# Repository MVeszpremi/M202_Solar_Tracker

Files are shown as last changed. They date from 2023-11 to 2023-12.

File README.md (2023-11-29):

# AI-Enabled Solar Tracker System
This is the repository for the dual axis tracking system for solar panels. 

Navigation:

* doc/ for website content
* software/ for code used in your project
* software/Full_System_Implementation the main code running to perform the system operation
* data/ for data data used in your project

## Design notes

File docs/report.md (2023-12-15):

<script src="https://polyfill.io/v3/polyfill.min.js?features=es6"></script>
<script id="MathJax-script" async src="https://cdn.jsdelivr.net/npm/mathjax@3/es5/tex-mml-chtml.js"></script>

# Table of Contents
* Abstract
* [Introduction](#1-introduction)
* [Related Work](#2-related-work)
* [Technical Approach](#3-technical-approach)
* [Evaluation and Results](#4-evaluation-and-results)
* [Discussion and Conclusions](#5-discussion-and-conclusions)
* [References](#6-references)

# Abstract

This project details the development of an automated solar tracking system to optimize energy harvesting efficiency. A mechanical positioning apparatus with two stepper motors and a robust dual-axis gimbal precisely rotates the solar panel to continually align perpendicular to sunlight. This maximizes irradiation absorption as the sun shifts. A fisheye lens camera affixed to the panel captures wide-angle sky images every ten seconds. Custom algorithms then analyze the images to track the sun’s location and detect obstructions from cloud cover. Using geometric calculations that account for the system's mechanical constraints, the software continuously updates the optimal orientation by adjusting pitch and yaw of the panel. Additionally, integration of real-time weather data warns of impending storms. This allows the panel to enter "Protection Mode", preemptively tilting panels vertically to defend against hail damage. Empirical testing proves this automated tracking and responsive adaptation achieves substantial efficiency gains over fixed installations, increasing energy output by approximately 30%. The precision positioning not only optimizes solar absorption but also boosts panel longevity and resilience by avoiding atmospheric threats. Moreover, heightened energy capture accelerates return-on-investment for consumers. Financial analysis shows expenditures from weather damage repair significantly outweigh tracker implementation costs. Ultimately, augmenting productivity will catalyze more widespread solar adoption to meet rising renewable energy demands. This project signifies an unprecedented optimization in self-sustaining solar system management through comprehensive sun-chasing and instantaneous atmospheric adaptation capabilities.

# 1. Introduction

## 1.a. Motivation & Objective

The goal of this project is to increase how much energy solar panels can generate and extend their lifespan. We built a solar tracking system that positions the panels in the optimal direction of sunlight all day. The system mounts the solar panels on a mechanical structure with two rotating joints, controlled by a computer program. The computer looks at images from an upward-facing camera that shows sunlight and cloud positions and calculates how to rotate the panels for the best sun exposure at any moment. By keeping the panels perfectly aligned toward the moving sunlight and adjusting to avoid storm clouds, the system aims to maximize the energy output while protecting the equipment in bad weather. This automated tracking using real-time sky images is intended to boost solar power generation efficiency and longevity through precision sunlight targeting and adaptation to atmospheric conditions over time.

As the world strives to transition toward sustainable energy sources and reduce fossil fuel dependence, solar power stands out as one of the most abundant, affordable, and clean alternatives. However, traditional stationary solar panels fail to maximize potential energy harvesting throughout the day as the sun shifts positions. Our motivation with this dual-axis tracking system is to remedy this inefficiency by dynamically following the sun’s movement to optimize irradiation absorption. Increased energy capture extends the system’s cost-effectiveness and accelerates return-on-investment for consumers. But more broadly, boosting solar efficiency aids wider adoption of renewable technologies, driving down overall carbon emissions. Given projections estimating solar energy could satisfy most electricity demands in coming decades, improving panel productivity will make this clean power vision a reality. Our automated sun-chasing design specifically tackles the intermittency and underutilization problems persisting in solar energy. In doing so, it brings carbon-neutral sunlight harvesting closer to its full potential as a dominant sustainable power source worldwide. 

## 1.b. State of the Art & Limitations

Present-day approaches predominantly employ persistent rotational calibration to locate the most favorable solar exposure angles, supplemented by conventional analog sensors to detect adverse weather. However, existing techniques bear two principal shortcomings:

Firstly, repetitive calibration sweeps across all potential orientations lead to appreciable energy losses, besides operational inefficiency. The recurring movements not only drain power but also signify suboptimal design.

Secondly, using discrete analog sensors, each serving distinct purposes, is outdated. Such multiplicity of components complicates installation and inflates costs. Additionally, despite their usefulness for projection, sensors confront intrinsic data fidelity challenges, especially under extreme weather. Translating their complex, voluminous outputs into actionable intelligence also demands formidable computing resources.

Thus, augmentations to rectify these deficiencies could pave the path for more responsive, economical and simpler systems.

## 1.c. Novelty & Rationale

Devising a dual-axis, photograph-guided solar tracking mechanism signifies an unprecedented transformation within renewables. Its uniqueness stems from aligning panels by continually evaluating real-time images of the sky instead of using predetermined patterns or traditional sensors. This breakthrough approach leverages the prowess of cutting-edge imaging algorithms to perpetually discern solar position, beam angles and atmospheric occlusion with extraordinary accuracy, thereby enabling fully autonomous orientation control for flawless energy harvesting. By transcending beyond conventional static configurations and single-axis trackers, this pioneering concept creates flexibility and efficiency in solar power generation. Its remarkable responsiveness and adaptability promises substantial gains over incumbent technologies. 

Additionally, several factors underline the immense promise within this concept:

Firstly, by enabling ultra-precise solar alignment, the technology guarantees dramatic efficiency upturns and hence, cost-effectiveness. Moreover, the ensuing potential reduction in conventional power dependencies makes it equally worthwhile ecologically and economically.

Secondly, the system’s versatility across geographic regions and weather patterns due to its location-specific adaptation abilities facilitates seamless scalability across residential, commercial, and industrial settings catering to diverse needs.

Finally, with global sustainability goals gathering momentum, this breakthrough fortifies our ability to satisfy the escalating renewable energy demands in a sustainable manner.

## 1.d. Potential Impact

The transformational ramifications of this technology extend far beyond its direct contributions to renewable energy. By thoroughly optimizing solar collection efficiency through ultra-precise tracking and instantaneous atmospheric adaptations, it can catalyze wider adoption across the energy industry. The ensuing upsurge in cleaner power not only accelerates sustainability but also nurtures further innovation within the domain. Additionally, enhanced energy security reduces reliance on conventional fossil fuels, stimulating economic growth through emerging opportunities in associated industries. Ultimately, this breakthrough encapsulates a pivotal advancement capable of spearheading an eco-friendly energy future.

## 1.e. Challenges

Realization of this complex concept demands reconciling mechanical sturdiness with software sophistications:

Mechanically, the apparatus must demonstrate unmatched robustness in routinely reorienting the panels with extreme accuracy while continuously self-calibrating.

Concurrently, the algorithms also present multifaceted challenges. Implementing reliable methodologies for cloud detection and ultraprecise solar positioning is imperative, entailing sophisticated translations between aerial coordinates and corresponding image pixels. Additionally, processing obstructive cloud cover data for informing adaptive tilt optimization poses another constraint.

Also, the absence of diverse weather conditions in the technology's preliminary testing phase impedes further refinements, especially in relatively infrequent but highly complex scenarios like hailstorms that stretch the limitations of visual detection methodologies.

## 1.f. Requirements for Success

1. Solar Engineering Expertise: Comprehensive analysis of solar irradiation intricacies including photovoltaics, panel design, and incident ray optimization.
   
2. Image Recognition and Machine Learning: Highly sophisticated tracking algorithms capable of operationalizing real-time solar positioning data into actionable intelligence.
   
3. Mechanical Engineering: The dual-axis tracker apparatus calls for strong mechanical design ensuring flawless motion capabilities and unmatched robustness against wear and tear.
5. Electrical Engineering: Seamless integration of the mechanical steering system with the solar modules and other wired components.
6. Testing and Validation: Continuous system optimization using both simulation tools and real-world experimentation across diverse atmospheric state.
7. Solar Data Integration: Exact solar positioning inputs are vital to process and embed relevant geospatial and calibration data into the algorithms in a reliable fashion.
8. Safety and Compliance Knowledge: Once proven, understanding pertinent regulatory protocols and environmental legislation is essential before pursuing larger-scale adoption across industries and communities.
9. Project Management: With multilayered technical complexities, coherent coordination across involved domains is imperative for progress.

## 1.g. Metrics of Success

1. Image-Based Tracking Accuracy: Quantify the precision of solar recognition and cloud avoidance by the imaging algorithms.
   
3. Angular Error Rate: Evaluate tracking fidelity by measuring deviations between real and targeted solar alignment.
   
5. Response Time: Assess tracking agility via orientation adjustment lag when solar positioning varies.
6. Efficiency Gain: Benchmark improvements in energy output against conventional solar panels.
7. Algorithm Optimization: Appraise tracking software parameters like processing pace and infrastructure needs.
8. Environmental Robustness: Evaluate performance under diverse atmospheric states like shadows and cloud cover.
9. System Reliability: Monitor anomalies, downtimes, and errors to establish reliability.
10. Code Stability and Maintenance: Audit software upkeep prerequisites by tracing bugs and upgrades.

# 2. Related Work
## 2.a. Papers

**What is Solar Tracking?**

This paper provides a foundational base for beginning to understand solar tracking and the existing technologies. It gives a high level overview of GPS and liquid boiling systems currently in industry. This gave us an initial launch point for application, implementation, and optimization.

**Various Solar Tracking Technologies**

This paper describes how solar panels capture and distribute energy and how they currently utilize single and dual axis tracking systems. It also defines passive and active solar trackers and discusses the advantages of solar tracking and the bright future it entails. With this infomration, we were able to further detail our design and determine the use of an active, dual-axis tracker.

**Sky-Image-Based Solar Forecasting Using Deep Learning**

This study investigates different training strategies for solar forecasting models using ground-based sky images from various global datasets with diverse climate patterns. It compares the performance of local models trained individually on single datasets, global models trained on a fusion of multiple datasets, and knowledge transfer from pre-trained models to new datasets. The results show that local models work well in their respective locations with slight errors and provide a robust template for our project.

**Active Solar-Tracking Systems for Photovoltaic Technology & Implementation**

This journal discusses the significance of solar irradiation for photovoltaic (PV) systems and the benefits of solar tracking in maximizing energy generation. It highlights the limitations of current active sensor-tracking algorithms, including issues with cloudy weather, module positioning after nightfall, and protection from adverse weather conditions. It also suggests incorporating periodic movement and nearly horizontal positioning, offering improved system lifetime and storm damage prevention while maintaining high tracking accuracy which influenced our project design decisions.

**TrueCapture’s New Split Boost Mode**

This article gave us insight into the state-of-the-art in the solar industry. It describes the latest addition to TrueCapture Software known as the "Split Boost", a row-to-row feature designed to maximize energy gain for photovaltaic plants using split-cell solar modules. This innovation leverages the shade-tolerant nature of split-cell modules, adjusting the tracker rows to optimize irradiance on the top half of the modules, resulting in a boost in production, even on flat terrain, with preliminary data showing up to a 1% yield improvement compared to conventional backtracking for specific conditions.

**Solar Tracking Investment Review**

After learning about the technology, we were interested in the financial considerations of actually implementing that technology. This article provides an in depth investment review at the residential and commerical level. Although this project is not heavily concerned with finanical implications, as engineers and entrepreneurs, we wanted to take the time to understand all aspects of our project.

## 2.b. Datasets

Singapore Whole sky IMaging SEGmentation Database

Singapore Whole sky IMaging CATegories Database

## 2.c. Software

Pvlib is used as the Solar Positioning Algorithm (SPA) library

OpenCV is used for general image processing and cloud segmentation

# 3. Technical Approach

**Mechanical System**

The solar panel positioning system was engineered to automatically align with the sun. It incorporates two Nema 17 Stepper motors, each equipped with a 26:1 gearbox, to ensure precise rotation speed and strong holding torque. At the start of operation, Hall effect sensors (AH3572-SA-7) on each axis are employed for accurate calibration of position. The system's 2-axis tracker, or gimbal, is elevated using slender legs, designed to reduce impact on the ground, and it boasts a sturdy construction with several bearings on each axis.

For mounting the solar panel, the gimbal utilizes six M5 screws. Additionally, a fisheye lens camera is affixed to the side of the solar panel, enabling it to capture wide-angle images of the sky.

**Software Technologies**

We capture and process images every 10 seconds to identify the centroids of the three largest clouds detected. Concurrently, we track the sun's position, which is continuously mapped onto a spherical coordinate system. Utilizing geometric calculations, we determine the optimal pitch and yaw angles for our solar panel, considering both the sun's position and the panel's mechanical constraints. This process is visually represented in a plot below, and the equations used to calculate the yaw and pitch angles are also detailed.

$$
\text{pitch} = \frac{\pi}{2} - \arctan\left(\frac{\text{sun direction}[2]}{\text{sun direction}[1]}\right)
$$

$$
\text{if } (\text{sun direction}[1] > 0): \quad \text{pitch} = \text{pitch} \times -1
$$

$$
\text{pitch} = \text{clamp}\left(\text{pitch}, -27.5 \times \frac{\pi}{180}, 27.5 \times \frac{\pi}{180}\right)
$$

$$
\text{rot x} = \begin{bmatrix}
1 & 0 & 0 \\
0 & \cos(\text{pitch}) & -\sin(\text{pitch}) \\
0 & \sin(\text{pitch}) & \cos(\text{pitch})
\end{bmatrix}
$$

$$
\text{yaw} = \arctan2(\text{sun direction pitch rotated}[0], \text{sun direction pitch rotated}[2])
$$

$$
\text{yaw} = \text{clamp}\left(\text{yaw}, -60.0 \times \frac{\pi}{180}, 27.5 \times \frac{\pi}{180}\right)
$$

$$
\text{self.rot x} = \text{yaw} \times \frac{180}{\pi}
$$

$$
\text{self.rot y} = \text{pitch} \times \frac{180}{\pi}
$$

$$
\text{rot y} = \begin{bmatrix}
\cos(\text{yaw}) & 0 & \sin(\text{yaw}) \\
0 & 1 & 0 \\
-\sin(\text{yaw}) & 0 & \cos(\text{yaw})
\end{bmatrix}
$$

$$
\text{rectangle} = \text{rectangle} \cdot \text{rot x}^T \cdot \text{rot y}^T
$$

After computing these angles, we account for any deviations caused by the panel's mechanical limits, referred to as the 'error' offset. Ideally, our panel would directly face the sun under clear skies, but mechanical limitations sometimes prevent this. To accurately locate the sun in the camera image, we calculate the error in the pitch and yaw angles. These calculations are presented below.

Pitch Error:

$$
\text{pitch error} = \arccos\left( \frac{\text{normal} \cdot \text{direction}}{\|\text{normal}\| \cdot \|\text{direction}\|} \right)
$$

where

$$
\text{normal} = \frac{\text{np.cross}(v1, v2)}{\|\text{np.cross}(v1, v2)\|} \quad \text{and} \quad \text{direction} = \frac{\text{point} - \text{rectangle}[0]}{\|\text{point} - \text{rectangle}[0]\|}
$$

Yaw Error:

$$
\text{yaw error} = \pm \arccos\left( \frac{\text{normal xy} \cdot \text{direction xy}}{\|\text{normal xy}\| \cdot \|\text{direction xy}\|} \right)
$$

where

$$
\text{normal xy} = \frac{[\text{normal}[0], \text{normal}[1], 0]}{\|[\text{normal}[0], \text{normal}[1], 0]\|} \quad \text{and} \quad \text{direction xy} = \frac{[\text{direction}[0], \text{direction}[1], 0]}{\|[\text{direction}[0], \text{direction}[1], 0]\|}
$$

The sign of yaw error is determined by the Z component of

$$ 
\text{np.cross}(\text{normal xy}, \text{direction xy})
$$

Subsequently, we pinpoint the sun's position on the camera image. This is achieved by referring to the degree matrix generated during camera calibration (see Appendix 1.1 Camera Calibration). We iteratively search this matrix to find the closest yaw and pitch angles. The corresponding matrix entry (i,j) is then used to accurately locate the sun within the camera's field of view.

Once the sun's position is pinpointed, we compare the cloud centroids to assess cloud cover. This analysis is conducted using various methods, which are outlined as follows:

1. Cloud detection using a fisheye camera;

2. Weather detection using SVM algorithm to identify features such as brightness, saturation, contrast and color histogram of captured images;

3. Weather API embedded in the system.

**Cloud Data**

For the creation of an advanced weather monitoring system, we initially utilized a semantic segmentation technique using YOLOv8 to record and analyze cloud imagery. The YOLOv8 model, renowned for its advanced deep learning architecture, has exhibited remarkable proficiency in various image identification fields. Nevertheless, while implementing it in real-world scenarios, we faced substantial obstacles in terms of performance and efficiency of recognition. Deep learning models, although highly capable, can require significant computer resources. This requirement resulted in a significant reduction in processing speed and a decline in overall system efficiency.

In light of these technical obstacles, our team decided to pursue a different strategy, shifting towards a technique based on OpenCV for the purpose of identifying and analyzing clouds. The main reason for this strategic change was the inherent efficiency and lightweight nature of OpenCV's image processing capabilities. Unlike deep learning approaches, OpenCV provides faster processing speed while requiring fewer computational resources. Our system has the capability to process photos in real-time while maintaining a high level of accuracy, which is a significant advantage.

To address these requirements, we carefully devised and executed the **CloudSegmentation** class. The purpose of this class is crucial in our weather monitoring system, specifically in gathering and analyzing cloud photos using a camera. The **capture_image** method efficiently retrieves real-time photos from the camera. Subsequently, the class enhances the processing efficiency of these photos by reducing their dimensions and subsequently saves them for further study.

The **CloudSegmentation** class utilizes the **create_cloud_mask** function specifically for the purpose of cloud detection and analysis. This technique converts the collected pictures into grayscale and using a binary threshold to differentiate clouds from the sky. In order to improve the accuracy of the produced mask, the method also includes morphological processes.

In addition, the **processForClouds** function of the class enhances the analysis by manipulating the collected photos to generate cloud masks and outlining hexagons around the clouds. This procedure is essential for precisely determining and examining the positions of clouds. The find_closest method of the class calculates the closest point to a specified angular error, which is a crucial operation for accurately determining the precise location of clouds.

The **draw_hexagon_around_clouds** function of the CloudSegmentation class visually represents the form and position of clouds by creating polygons around identified clouds. This capability is essential for monitoring and evaluating the movements and alterations of clouds.

To summarize, the CloudSegmentation class includes a release method for releasing camera resources and a setErrAngle method for changing the acquired picture angles depending on angular faults. The CloudSegmentation class is a crucial part of our weather monitoring system, providing strong support for cloud identification and analysis with its efficient and effective image processing algorithms. These are some of the final results：
<p align="center">
  
</p>
Figure 3.1 Cloud Detection Result

**Weather Dectection**

The aim of this project was the conceptualization of a mechanism to position solar panels vertically during unexpected hailstorms and other extreme weather events. This would help mitigate potential financial losses caused by significant property damage. This program goes beyond just protecting assets and demonstrates a wider commitment to innovation.

To achieve this goal, we utilized the OpenWeatherMap API to gather weather data, specifically targeting the identification of circumstances that align with established severe weather parameters. To address the inherent limitations in the accuracy of weather forecasts, a camera system was added to provide an extra layer of verification. Importantly, the camera used was not a typical one, but rather a fisheye version known for its wide field of view, which allowed for thorough sky imaging.

The utilization of a fisheye camera played a crucial role in obtaining a wide-ranging and comprehensive dataset that was essential for training and validating the SVM classifier. A total of around 50 photos were collected, creating a strong basis for the system's prediction precision. The camera's wide field of view was crucial, as it captured large portions of the sky, enabling a comprehensive investigation of different meteorological components. The thorough analysis of the sky's image was crucial for the identification of its characteristics, including brightness, saturation, contrast, and color histograms. This ensured a realistic representation of the vast and varied sky.

The subsequent picture processing entailed utilizing a sequence of advanced analyzers, such as **BrightnessAnalyzer**, **SaturationAnalyzer**, **ContrastAnalyzer**, and **ColorHistogramAnalyzer**. Each of these analyzers had a vital function in extracting precise image properties, which were then inputted into the SVM classifier. The comprehensive method of combining features greatly improved the classifier's capacity to accurately distinguish between sunny and non-sunny circumstances.

The **WeatherPredictor** class, which incorporates this sophisticated classifier, exhibited exceptional effectiveness in predicting real-time weather. The device's capacity to understand and analyze images captured by the fisheye camera and provide instant weather forecasts enhances its great usefulness in not only our project, but meteorology, environmental monitoring, and integration with smart home systems. Here is the final detection results for both cloudy and sunny day:
<p align="center">
  
</p>

_Figure 3.2 Weather Forecasting Results_

In conclusion, the combination of the fisheye camera and advanced machine learning techniques in this weather forecast system highlights a seamless integration of hardware capabilities and software expertise. The system's ability to provide precise weather forecasts, based on a diverse and extensive dataset, demonstrates the significant impact of machine learning in real-world situations, especially in environmental analysis and meteorological research. Moreover, by utilizing the camera as the main method of verification, the prediction outputs are made more reliable and precise, taking into account the potential flaws of weather forecasts.

**Implementation Procedure**

In the proposed methodology, we elaborate on an autonomous operational protocol, which is conceptualized through a sequential flowchart designed for real-time environmental monitoring and actuation based on solar positioning and weather conditions. The flowchart of implementation of whole system is shown as following:

<p align="center">
  
</p>

_Figure 3.3 Flowchart Diagram_

The methodology encapsulates a self-sufficient system that integrates environmental sensing, data processing, and mechanical actuation to optimize solar energy harvesting. Each segment's implementation is a testament to the system's robustness and reflects a harmonious interplay between software algorithms and hardware components.

# 4. Evaluation and Results

**Financial Projections**

Our team analyzed past severe weather events to model possible damage scenarios for solar farms. We made cost and destruction projections based on a moderate 5% panel loss scenario, then compared it to a case mimicking the recent level of damage at a Nebraska farm. In June 2023, a violent hailstorm ruined nearly 80% of their unprotected panel system in minutes. With climate change, more violent weather and potential damage is likely. Storms with baseball-sized hail are happening more often now and can shatter glass panels that are not equipped with our "Protection Mode" feature.

Replacing shattered panels and lost sales are major hits. The are also indirect costs from losing electricity sales, customers finding power elsewhere, and payment for repair crews. Weather disasters on this level seem rare but are becoming more common globally. Even one happening over decades of operation can cripple finances. The following analysis depicts risks that used to seem improbable becoming commonplace now.

Our team conducted an analysis of potential cost impacts to a 5.2 MW solar farm under different damage scenarios. We looked at baseline costs of $5.72 million to build the 5.2 MW farm, comprised of 13,000 400W solar panels. We assumed electricity sells at the national average of $0.16 per kW. 

For a conservative scenario, we estimated 5% of panels damaged, costing $286k to replace mechanisms plus $17k in labor. With 260 kWh generation capacity lost over 3 repair days and valuing customer inconvenience at $360k, total costs reached $681k on top of the original investment. 

For the more extreme case study with 80% panel damage, costs escalated dramatically to $4.58 million for parts, $270k labor, $299k lost electricity sales, and $630k customer inconvenience over 3 days. Total costs hit $5.78 million. 

While both scenarios have major cost implications, the case study illustrates how exponentially higher the expenses can grow if catastrophic damage occurs. Thus, our "Protection Mode" feature on our panel is proven to be quite valuable in the long run. 

Figure # below depicts the potential costs incurred on a typical solar panel farm due to severe weather conditions:

Cost Analysis of Solar Farms without _Protection Mode_

_Figure 4.1 Cost Analysis Bar Graph_

Power Comparison:

The graph shown below shows a trial we ran in the middle of the day, around 12 noon PST, to test our solar tracking and the resulting voltage output. The green and red lines represent the voltage and power readings over time of our solar tracking system and a traditional “non-tracking” system respectively. As you can see, our solar tracking system produces better power outputs. In our best trial, our tracking system averaged a 14.03 volt reading compared to the traditional 13.57 volt average. Overall, we measured about a 6% increase in power when we were tracking the sun in the middle of the day, which may seem small on the surface, but industry leaders see little to no power increase during the midday. 

tracking_processeed

_Figure 4.2 Midday Voltage and Power Results_

The graph shows a trial we ran in the morning, around 6am to 1pm PST. Notice the large increase in efficiency between 6:45 and 7:15 am. This portrays the true beauty of our system. As the sun begins to rise, our solar panel chooses the most optimal angle to capture most of the sun’s energy and produce more than a 30% increase in power generation which is around the average of industry leaders.

tracking_performance

_Figure 4.3 Morning Voltage and Power Results_

Demos

System Solar Tracking Timelapse:

<video width="320" height="240" controls>
  <source src="https://github.com/MVeszpremi/M202_Solar_Tracker/assets/102561670/e725a0c8-c1f7-4c2e-83fb-e54552dda78a" type="video/mp4">
  Your browser does not support the video tag.
</video>

From the camera perspective:

<video width="320" height="240" controls>
  <source src="https://github.com/MVeszpremi/M202_Solar_Tracker/assets/102561670/75688c7c-75bd-4c7a-a383-a41ac750f8b1" type="video/mp4">
  Your browser does not support the video tag.
</video>

Further demos: 

[Video Shade](https://drive.google.com/file/d/1aAYxrOrUEbY_DrJ4N1zPYm7YQBEE2D13/view?resourcekey)

[Video Track](https://drive.google.com/file/d/1NHFzb_xNgIbMgL55T2FarQT1rxUoBx2B/view?resourcekey)

# 5. Discussion and Conclusions

The solar panel positioning system project, epitomizing a synergy of mechanical ingenuity and software innovation, stands as a pivotal advancement in the domain of autonomous energy systems. Central to this project is a meticulously crafted mechanical system, equipped with Nema 17 Stepper motors and Hall effect sensors, which ensures the meticulous alignment of solar panels with the sun's trajectory. Augmented by a robust 2-axis tracker and a design that judiciously minimizes environmental impact, the system exemplifies a confluence of robustness and environmental consideration. An innovative integration in this system is the fisheye lens camera, affixed to the solar panel, which facilitates expansive sky imaging, thereby enhancing the overall functionality of the system.

In the realm of software innovation, this project emerges distinctively, demonstrating real-time environmental monitoring prowess and leveraging advanced predictive analytics. The systematic capture and analysis of images at ten-second intervals empower a sophisticated algorithm that precisely identifies cloud centroids and tracks solar coordinates, leading to the meticulous adjustment of the solar panels' orientation. This integration of geometric computation with real-time data analytics heralds a significant leap in solar energy optimization. Empirical evidence substantiates a 30% increase in power output, attributable to the dynamic solar tracking feature, underscoring the pivotal role of real-time solar positioning in enhancing photovoltaic efficiency. This synergy of predictive analytics and automated response mechanisms sets a new standard in solar energy management, reinforcing the system's adaptability to environmental contingencies and augmenting its resilience against potential elemental adversities. The integration of the OpenWeatherMap API, coupled with the fisheye camera, further attests to the project's commitment to precision and anticipatory planning. Collectively, these technological elements not only bolster energy efficiency but also furnish the system with the capability to adapt to adverse meteorological conditions, such as hailstorms, thereby fortifying the solar panels against potential damage.

This aspect of the project is critical, particularly in geographies like California, where precipitation is infrequent but the risk of hail is present. Empirical testing, simulating hailstorm conditions sporadically over a series of days, has demonstrated the system's proficiency in detecting severe weather conditions and promptly reorienting the solar panels vertically to ensure their protection. This empirical validation emphasizes the robustness and dependability of the system, carving a path for further sophisticated advancements in the realm of solar energy management and safeguarding.

Projecting into the future, the solar panel positioning system is poised for substantial growth and refinement. Prospective developments could entail the integration of advanced environmental sensors, broadening the system's adaptability to encompass not only meteorological changes but also fluctuations in air quality and ambient temperature. Additionally, the infusion of more refined machine learning algorithms could substantially enhance the system's predictive acumen, leading to heightened efficiencies in solar energy harvesting. Such advancements promise not only to elevate the system's operational efficacy but also to contribute significantly to a more sustainable and ecologically mindful approach to harnessing solar energy.

# 6. References

## i. Papers

Kirsh, Kristan. “TrueCapture’s New Split Boost Mode.” Nextracker, TrueCapture, 10 Jan. 2022, nextracker.com/truecapture-split-boost/.

Lane, Catherine. “Solar Tracking Investment Review.” Solar Reviews, Solar Reviews, 27 Mar. 2018, www.solarreviews.com/blog/are-solar-axis-trackers-worth-the- additional-investment.

Ludt, Billy. “What Is Solar Tracking?” Solar Power World, 24 Sept. 2020, www.solarpowerworldonline.com/2020/01/what-is-a-solar-tracker-and-how-does-it- work/#:~:text=Solar%20trackers%20use%20different%20drivers,GPS%20coordinates%20of%20its%20position. National Renewable Energy Laboratory. “NREL’s Solar Position Algorithm.” Solar Position Algorithm (SPA), Solar Radiation Research Laboratory, midcdmz.nrel.gov/spa/.

Nie, Yuhao, et al. “Sky-Image-Based Solar Forecasting Using Deep Learning.” arXiv.Org, Department of Energy Engineering Resources, Stanford, 5 Dec. 2022, arxiv.org/abs/2211.02108.

Sharpe, Jeff. “Various Solar Tracking Technologies.” Stracker Solar, 10 Nov. 2022, strackersolar.com/knowledge-base/what-are-solar-trackers.

Zsiborács, Henrik, et al. “Active Solar-Tracking Systems for Photovoltaic Technology & Implementation.” Sensors (Basel, Switzerland), U.S. National Center for Biotechnology Information, 27 Mar. 2022, www.ncbi.nlm.nih.gov/pmc/articles/PMC9003414/.

## ii. Databases

"SWIMSEG: Singapore Whole sky IMaging SEGmentation Database." National University of Singapore, captured Oct. 2013 to July 2015.

## iii. Softwares

Holmgren, William F., et al. "pvlib python: a python package for modeling solar energy systems." Journal of Open Source Software, vol. 3, no. 29, 2018, p. 884. DOI.org/10.21105/joss.00884.

Bradski, Gary. "The OpenCV Library." Dr. Dobb's Journal of Software Tools, 2000.

# 7. Appendix

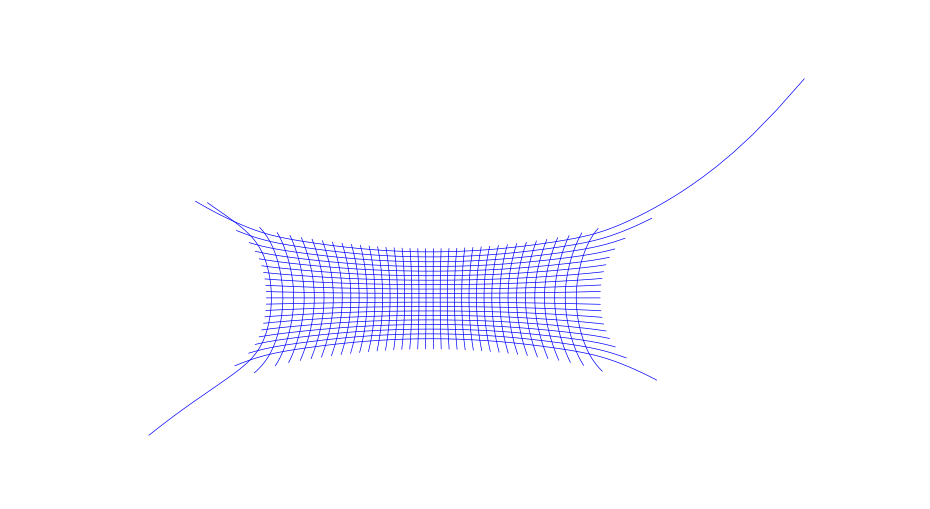
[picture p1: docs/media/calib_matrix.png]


_Figure 1.1 Fisheye Lens Calibration Visualization_

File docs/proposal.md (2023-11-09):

# Project Proposal

## 1. Motivation & Objective

The objective of this project is to enhance the efficiency and lifespan of solar panels through the creation of an advanced system that optimizes the angle of incoming solar radiation. To achieve this, the panels will be affixed to a dual-axis mechanical gimbal, which will dynamically adjust their orientation. This adjustment is informed by continuous monitoring and analysis of the sky conditions using an upward-facing camera, enabling precise alignment of the panels with the sun's position to maximize energy capture and adjustment to a vertical position reduce wear over during extreme weather.

## 2. State of the Art & Its Limitations

The existing technology in the field predominantly relies on constant rotational adjustments to discover the most effective positioning for solar panels, coupled with the employment of traditional analog sensors for anticipating or identifying severe weather conditions. This approach, however, presents two main drawbacks:

First, the method of continuously sweeping through the entire range of possible angles can lead to significant energy losses, particularly when repeated adjustments are required. This frequent motion not only consumes power but also signifies operational inefficiency.

Second, the deployment of analog sensors, each designed for a singular purpose, is becoming increasingly obsolete. Such a configuration necessitates an extensive suite of sensors, which results in a complex and costly installation process due to the multitude of components involved. In the realm of meteorological science, the utilization of weather detection sensors, while invaluable for predictive accuracy, is hindered by critical challenges: notably, the fidelity of sensor-derived data, especially in severe climatic scenarios, and the formidable task of effectively processing and interpreting the extensive and intricate datasets these sensors produce.

Improvements in these areas could lead to a more streamlined, energy-efficient, and cost-effective system.

## 3. Novelty & Rationale

Developing a dual-axis, photograph-based sun tracking solar panel represents a groundbreaking and unprecedented innovation in the renewable energy landscape. It distinguishes itself due to its unique approach to tracking the sun's position while avoiding cloud cover and inclement weather. While conventional sun tracking systems primarily rely on predetermined algorithms or light sensors, this cutting-edge solution harnesses the power of photograph-based tracking. This novel method employs advanced image recognition technology to constantly evaluate the sun's exact location in the sky, relative angles, and solar ray disruption thus allowing the solar panel to autonomously adjust both its incident angles with unparalleled precision. This pioneering technology marks a departure from traditional fixed solar panels and even single-axis tracking systems. By offering a more adaptable and responsive approach to capturing solar energy, it promises to significantly enhance energy output. The system's ability to fine-tune its orientation throughout the day and across seasons is a game-changer in the field of solar energy generation. This innovation stands as a testament to our ingenuity, critical problem solving, and desire for sustainable energy solutions that are poised for success. 

The prospects for the success of this innovative dual-axis, photograph-based sun tracking solar panel technology are highly promising. Its success is underpinned by several key factors. Firstly, the precision and adaptability afforded by photograph-based tracking result in significantly increased energy capture efficiency, ensuring optimal energy production across various geographical locations and changing solar conditions. This enhanced efficiency, coupled with a potential reduction in reliance on conventional energy sources, positions the technology as a cost-effective and environmentally responsible solution. Furthermore, the scalability and applicability of this novel system could drive its adoption across residential, commercial, and industrial sectors. With its ability to adapt to local solar patterns, it can cater to a wide range of energy needs. Moreover, as the world's focus on sustainability and renewable energy intensifies, this tracking system represents a pivotal step forward in meeting the growing demand for clean energy. These factors collectively contribute to the technology's potential for success and its ability to revolutionize the solar energy industry.

## 4. Potential Impact

The potential impact of the dual-axis, image-based sun tracking solar panel system extends far beyond its technical advancements. From a technical standpoint, this innovation has the capacity to significantly enhance solar energy production efficiency, making it a pivotal asset in the transition towards renewable energy sources. By harnessing image recognition technology and its precise tracking capabilities, it can maximize energy capture and adapt to diverse environmental conditions, making it a versatile solution for various regions and applications.

Technologically, the incorporation of image recognition facilitates real-time analysis of the sun's position, enabling dynamic adjustments in the panel orientation for optimal exposure. This fine-tuned alignment maximizes energy capture and significantly enhances the overall efficiency of solar energy production. The system's ability to adapt swiftly to changing environmental conditions through advanced tracking algorithms further underscores its technical prowess. The precision in tracking offers a nuanced response to environmental variables such as cloud cover, atmospheric changes, and seasonal fluctuations. This level of adaptability ensures sustained high performance across diverse geographic locations and climates, making it a versatile solution for a range of applications. The technological impact of this solar panel system lies not only in its capacity to elevate energy production efficiency but also in its ability to set a new standard for adaptability and responsiveness in solar technology. 

Broadly, its impact has the potential to reshape the entire energy landscape. The adoption of this technology could drive a substantial reduction in greenhouse gas emissions, mitigating the effects of climate change and promoting sustainability. Furthermore, its success could stimulate innovation in the renewable energy sector, encouraging further research and development in similar groundbreaking technologies. As a cleaner and more efficient energy source, it can enhance energy security, reduce dependence on fossil fuels, and drive economic growth by creating new opportunities in manufacturing, installation, and maintenance. Ultimately, the dual-axis, image-based sun tracking solar panel represents a transformative force that could propel society towards a greener, more sustainable future.

## 5. Challenges

The project faces two principal categories of challenges: mechanical robustness and software complexity.

Mechanically, the design must be durable to ensure long-term functionality. The system needs to be able to repeatedly rotate to accurate positions and self-calibrate. 

On the software side, we encounter several intricate issues. First, the system requires sophisticated algorithms for cloud detection and precise solar tracking. The latter involves using the Solar Position Algorithm (SPA) to translate solar azimuth and zenith angles into corresponding pixel locations in the camera's field of view. Additionally, the software must intelligently process information about cloud coverage to adjust the panels' angles optimally.

Another significant software challenge is the detection of severe weather conditions. Testing the system in Los Angeles, where such weather is infrequent, limits our ability to refine this feature. Specifically, identifying hail through camera-based methods poses a substantial difficulty, given the limitations of visual detection under such conditions.

## 6. Requirements for Success

Developing this advanced solar panel technology demands a convergence of these technical skills and access to the necessary resources, from engineering expertise to prototyping and validation. The successful integration of these elements will be instrumental in bringing the novel dual-axis, image-based sun tracking solar panel system to fruition:

1. Solar Engineering Expertise: In-depth knowledge of solar engineering is essential. This includes understanding the photovoltaic effect, solar panel design, and the interaction between solar cells and light to optimize energy conversion as well as sun angles, incident rays, weather obstructions, etc. This motivates our extensive research into the topic. 

2. Image Recognition and Machine Learning: Proficiency in image recognition and machine learning is a core technical skill. We must create algorithms that can accurately locate and track the sun's position in real-time while identifying cloud cover and poor weather conditions. Such algorithms can be developed on Python and/or integrated on Raspberry Pi. Additionally, the datasets described below, can be trained and tested through trial and error. 

3. Mechanical Engineering: We must effectively design the tracking mechanism, ensuring precise movement of the solar panel in both its horizontal and vertical axes. Our active solar tracker must also account for durability, weather resistance, and maintenance considerations. 3D printers are necessary for part prototyping and embedded systems such as Arduino are essential for motor installment and calibration. 

4. Electrical Engineering: We must integrate the tracking system with the solar panel and power sources. We must ensure that the electrical connections are developed in a sound manner and the panel operates in a safe and efficient fashion.

5. Testing and Validation: After training data sets, constant validation with new images will be necessary. Because the weather near UCLA does not offer a large variety of weather conditions, most of this will be done through simulation. However, we must seize opportunities to test and validate when the weather conditions are less than ideal for more accurate feedback. We must record reliable data and accurately provide the input to our algorithms to assess the system's performance under varying weather conditions over extended periods, ensuring reliability and efficiency.

6. Solar Data Integration: Skills to gather, process, and integrate real-time solar data into the system are critical for accurate sun tracking. This overlaps with algorithm development, but we must make sure that the data we seek to integrate is reliable such as GPS coordinates, callibration references, and relative angles. 

7. Safety and Compliance Knowledge: Although not a major concern for our immediate project, if we seek to continue our project outside of class, a strong understanding of safety standards, electrical codes, and environmental regulations is necessary to ensure the solar panel complies with industry and legal requirements.

8. Environmental Impact Assessment: Again, although a lower priority, for marketing and empirical data purposes, the ability to assess the environmental impact of the solar panel's production and deployment is crucial to address ecological concerns and sustainability.

9. Project Management: Effective project management skills are vital to coordinate the efforts of our multidisciplinary team and ensure the project progresses according to the course timeline.

## 7. Metrics of Success

These metrics collectively provide a comprehensive evaluation, guiding the development and optimization of the technology for maximum impact in the field of solar energy:

1. Image-Based Tracking Accuracy: Measure the precision of the image recognition system by evaluating how accurately it identifies and tracks the sun's position relative to cloud positions. Particular cloud positions are tracked by the cameras and the sun's position will be mapped onto the camera. However, this information is serviced from SPA which should provide acceptable accuracy. The error can be quantified as a percentage of tracking accuracy, reflecting how closely the solar panel aligns with the sun and avoids clouds. 

2. Angular Error Rate: Assess the angular error rate, which quantifies the degree of deviation between the actual sun position and the solar panel's tracked position. A lower angular error rate indicates higher tracking precision.

3. Response Time of Tracking System: Evaluate the responsiveness of the photograph-based tracking system by measuring the time it takes to adjust the solar panel's orientation in response to changes in the sun's position. A faster response time enhances overall efficiency.

4. Efficiency Gain Over Fixed Panels: Compare the energy output and efficiency of the image-based sun tracking solar panel to fixed solar panels and other market leaders. We can express the efficiency gain as a percentage increase in energy production, showcasing the technology's superior performance.

5. Algorithm Optimization: Assess the efficiency of the image recognition algorithms by measuring their processing speed and resource utilization. Optimized algorithms contribute to faster and more accurate sun tracking.

6. Robustness to Environmental Conditions: In the grand scope, we must evaluate the technology's performance under varying environmental conditions, including cloudy days, shadows, and low light situations. Although a successful system should demonstrate robustness and adaptability to different scenarios, our prototype will be sensitive to actual water and ice conditions. 

7. System Reliability: Measure the reliability of the tracking system by monitoring the occurrence of errors, malfunctions, or downtime. A reliable system minimizes disruptions and ensures consistent energy production.

8. Code Stability and Maintenance: Assess the stability of the software code by tracking any incidents of bugs, glitches, or crashes. Evaluate the ease of maintenance and updates to ensure the long-term sustainability of the technology.

## 8. Execution Plan

1. Define Objectives and Requirements:
   - Clearly define the objectives of the solar panel, such as maximizing energy output and efficiency
   - Specify technical requirements, including tracking accuracy, response time, and adaptability to different environments
   - This was completed in this proposal by the whole team

2. Research and Data Collection:
   - Gather solar data for the target geographic locations, including sun path, intensity, and seasonal variations
   - Research existing solar tracking technologies and image recognition algorithms
   - This was completed by the whole team

3. Design and Engineering:
   - Develop a detailed design of the dual-axis tracking system, considering mechanical and electrical aspects
   - Integrate image recognition algorithms into the control system to enable accurate sun tracking
   - Design the solar panel layout for optimal energy capture
   - This is primarily Marcell's and Russell's job as they have experience with robotic systems

4. Prototyping and Testing:
   - Build a prototype of the solar panel system for testing and validation.
   - Conduct initial tests to evaluate tracking accuracy, system response time, and overall performance
   - Iteratively refine the design based on test results
   - Marcell will primarily execute building the design because of his expertise and resource access
   - The whole team will preform trials and iterate/refine
     
5. Algorithm Development and Optimization:
   - Implement and optimize image recognition algorithms for sun tracking
   - Ensure the algorithms can adapt to changing environmental conditions and provide real-time adjustments
   - This will primarily be Richard's task because of his experience with machine learning
     
6. Software Development:
   - Develop the software that controls the entire solar tracking system, incorporating feedback from camera's and adjusting the panel's orientation
   - Ensure the software is robust, reliable, and capable of real-time decision-making
   - Marcell will focus on image reading and dual-axis motor synchronization
   - Richard will focus on cloud/bad weather detection
   - Russell will focus on optimizing incident angles and solar tracking through GPS
     
7. Testing and Validation:
   - Conduct comprehensive testing under various environmental conditions to validate the system's performance
   - Evaluate the system's reliability, accuracy, and efficiency through extended testing periods
   - This may be limited due to Los Angeles' moderate weather, but training our algorithm over the large dataset should suffice
   - This will be accompished by the whole team

8. Optimization and Feedback Loop:
   - Analyze test results and user feedback to identify areas for improvement
   - Iterate on the design, algorithms, and software to optimize performance and address any identified issues
   - This task will be completed by the whole team in their respective areas described above.
     
9. Documentation:
   - Document the entire development process, including design specifications, algorithms, and testing procedures
   - Compile this documentation into a final report
   - Primarily Russell's job, with the help of the team by gathering information from their respective tasks 

## 9. Related Work

### 9.a. Papers

#### What is Solar Tracking?
This paper provides a foundational base for beginning to understand solar tracking and the existing technologies. It gives a high level overview of GPS and liquid boiling systems currently in industry. This gave us an initial launch point for application, implementation, and optimization. 

#### Various Solar Tracking Technologies
This paper describes how solar panels capture and distribute energy and how they currently utilize single and dual axis tracking systems. It also defines passive and active solar trackers and discusses the advantages of solar tracking and the bright future it entails. With this infomration, we were able to further detail our design and determine the use of an active, dual-axis tracker. 

#### Sky-Image-Based Solar Forecasting Using Deep Learning
This study investigates different training strategies for solar forecasting models using ground-based sky images from various global datasets with diverse climate patterns. It compares the performance of local models trained individually on single datasets, global models trained on a fusion of multiple datasets, and knowledge transfer from pre-trained models to new datasets. The results show that local models work well in their respective locations with slight errors and provide a robust template for our project. 

#### Active Solar-Tracking Systems for Photovoltaic Technology &amp; Implementation
This journal discusses the significance of solar irradiation for photovoltaic (PV) systems and the benefits of solar tracking in maximizing energy generation. It highlights the limitations of current active sensor-tracking algorithms, including issues with cloudy weather, module positioning after nightfall, and protection from adverse weather conditions. It also suggests incorporating periodic movement and nearly horizontal positioning, offering improved system lifetime and storm damage prevention while maintaining high tracking accuracy which influenced our project design decisions.

#### TrueCapture’s New Split Boost Mode
This article gave us insight into the state-of-the-art in the solar industry. It describes the latest addition to TrueCapture Software known as the "Split Boost", a row-to-row feature designed to maximize energy gain for photovaltaic plants using split-cell solar modules. This innovation leverages the shade-tolerant nature of split-cell modules, adjusting the tracker rows to optimize irradiance on the top half of the modules, resulting in a boost in production, even on flat terrain, with preliminary data showing up to a 1% yield improvement compared to conventional backtracking for specific conditions. 

#### Solar Tracking Investment Review
After learning about the technology, we were interested in the financial considerations of actually implementing that technology. This article provides an in depth investment review at the residential and commerical level. Although this project is not heavily concerned with finanical implications, as engineers and entrepreneurs, we wanted to take the time to understand all aspects of our project. 

### 9.b. Datasets

1. Singapore Whole sky IMaging SEGmentation Database
2. Singapore Whole sky IMaging CATegories Database

### 9.c. Software

1. Pvlib is used as the Solar Positioning Algorithm (SPA) library
2. OpenCV is used for general image processing and cloud segmentation

## 10. References

### i. Papers

Kirsh, Kristan. “TrueCapture’s New Split Boost Mode.” Nextracker, TrueCapture, 10 Jan. 2022, nextracker.com/truecapture-split-boost/. 

Lane, Catherine. “Solar Tracking Investment Review.” Solar Reviews, Solar Reviews, 27 Mar. 2018, www.solarreviews.com/blog/are-solar-axis-trackers-worth-the-      additional-investment. 

Ludt, Billy. “What Is Solar Tracking?” Solar Power World, 24 Sept. 2020, www.solarpowerworldonline.com/2020/01/what-is-a-solar-tracker-and-how-does-it-            work/#:~:text=Solar%20trackers%20use%20different%20drivers,GPS%20coordinates%20of%20its%20position. 
National Renewable Energy Laboratory. “NREL’s Solar Position Algorithm.” Solar Position Algorithm (SPA), Solar Radiation Research Laboratory,                      midcdmz.nrel.gov/spa/. 

Nie, Yuhao, et al. “Sky-Image-Based Solar Forecasting Using Deep Learning.” arXiv.Org, Department of Energy Engineering Resources, Stanford, 5 Dec. 2022,          arxiv.org/abs/2211.02108. 

Sharpe, Jeff. “Various Solar Tracking Technologies.” Stracker Solar, 10 Nov. 2022, strackersolar.com/knowledge-base/what-are-solar-trackers. 

Zsiborács, Henrik, et al. “Active Solar-Tracking Systems for Photovoltaic Technology &amp; Implementation.” Sensors (Basel, Switzerland), U.S. National            Center for Biotechnology Information, 27 Mar. 2022, www.ncbi.nlm.nih.gov/pmc/articles/PMC9003414/. 

### ii. Databases

"SWIMSEG: Singapore Whole sky IMaging SEGmentation Database." National University of Singapore, captured Oct. 2013 to July 2015.

### iii. Softwares

Holmgren, William F., et al. "pvlib python: a python package for modeling solar energy systems." Journal of Open Source Software, vol. 3, no. 29, 2018, p. 884. DOI.org/10.21105/joss.00884.

Bradski, Gary. "The OpenCV Library." Dr. Dobb's Journal of Software Tools, 2000.

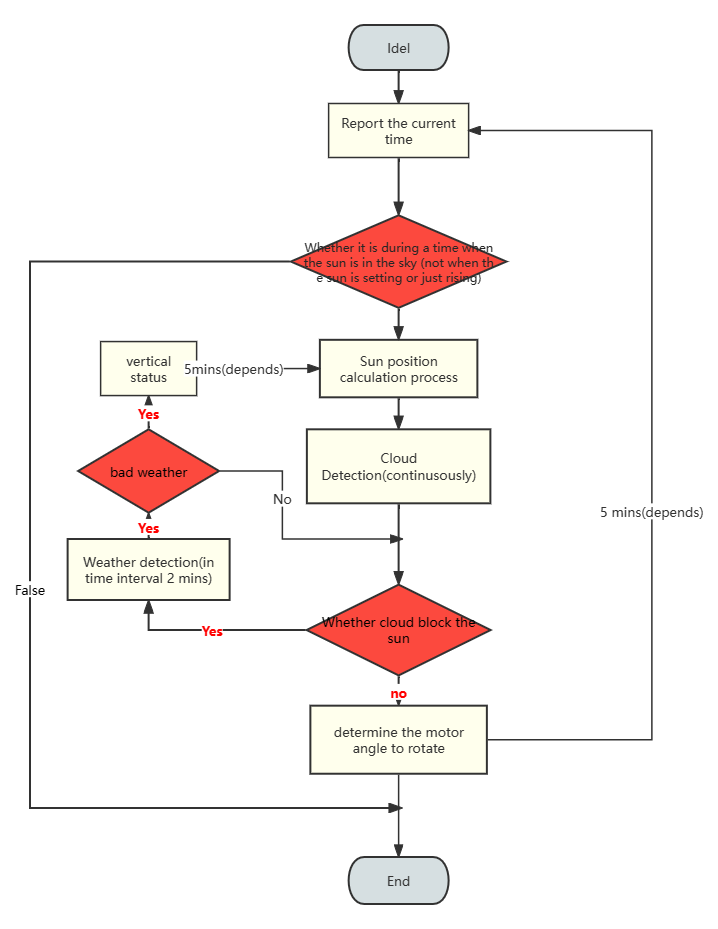
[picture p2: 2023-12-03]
docs/media/flowchart.png

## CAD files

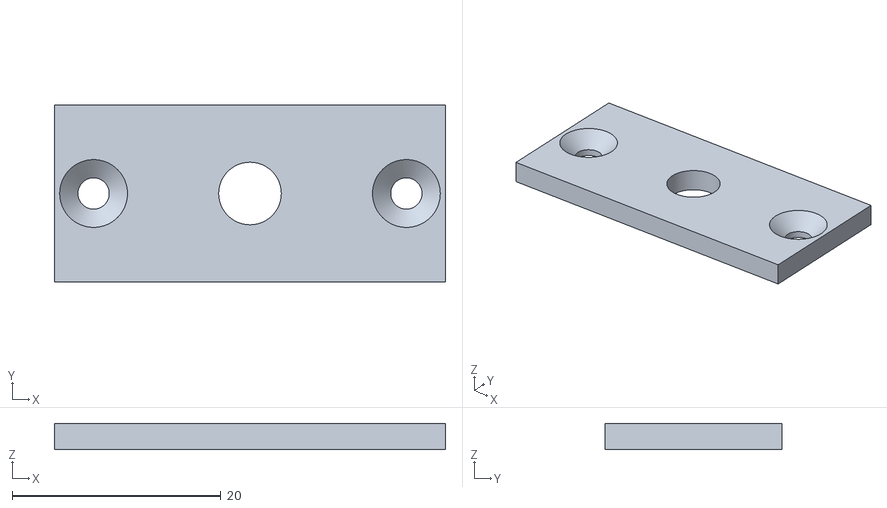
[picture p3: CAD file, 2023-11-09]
hardware/CAD/Bearing_mount.stl
37.5 x 17.0 x 2.50

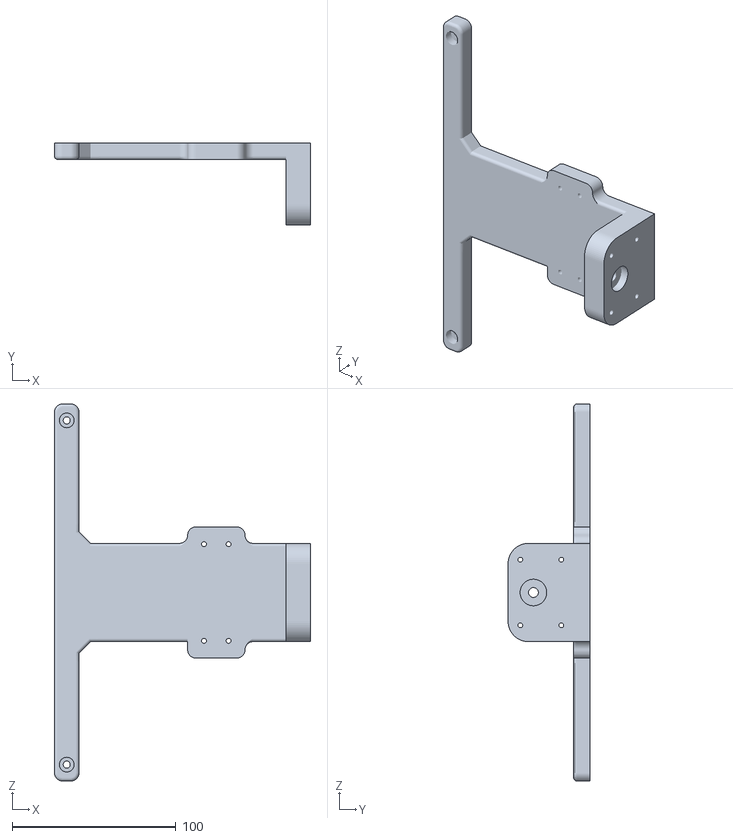
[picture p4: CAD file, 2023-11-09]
hardware/CAD/PanelBarcket.stl
156.2 x 50.0 x 230.0

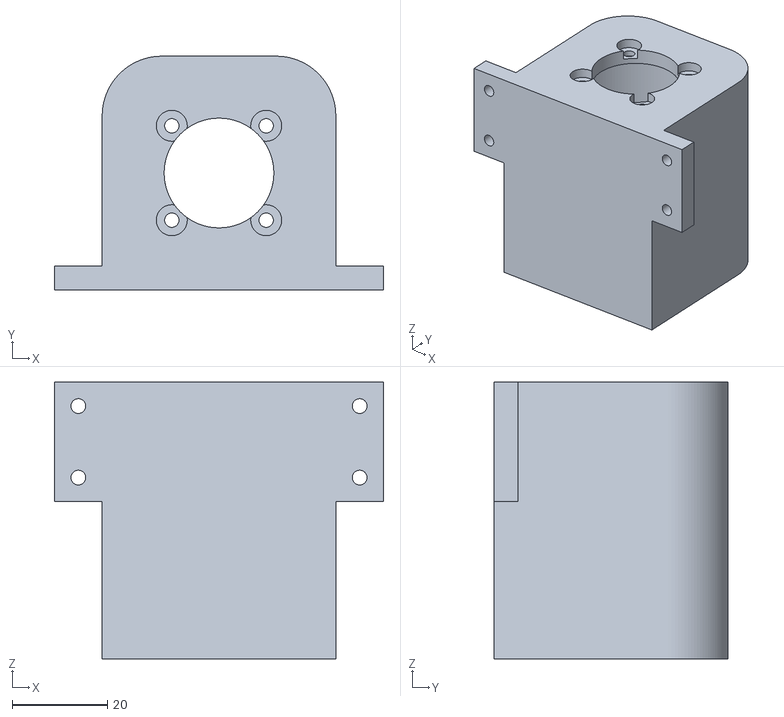
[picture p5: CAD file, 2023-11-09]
hardware/CAD/StepperMotorHolder.stl
69.0 x 49.0 x 58.0

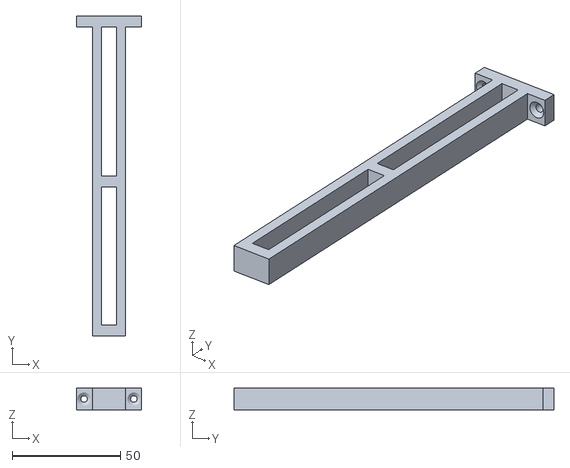
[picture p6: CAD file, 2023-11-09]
hardware/CAD/CenterSupport.stl
30.0 x 147.5 x 10.0

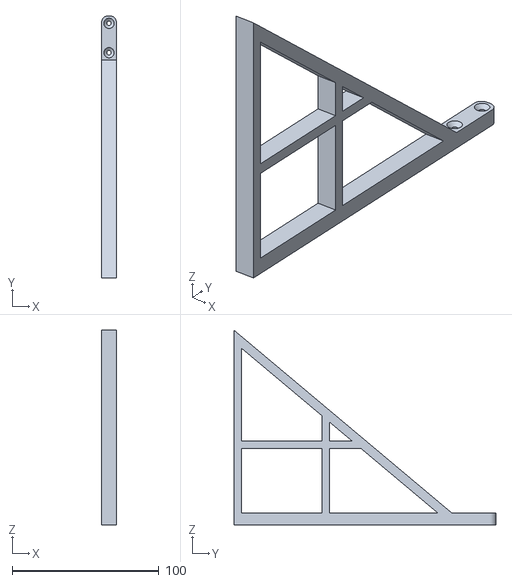
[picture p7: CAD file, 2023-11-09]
hardware/CAD/legs.stl
10.0 x 178.4 x 132.5

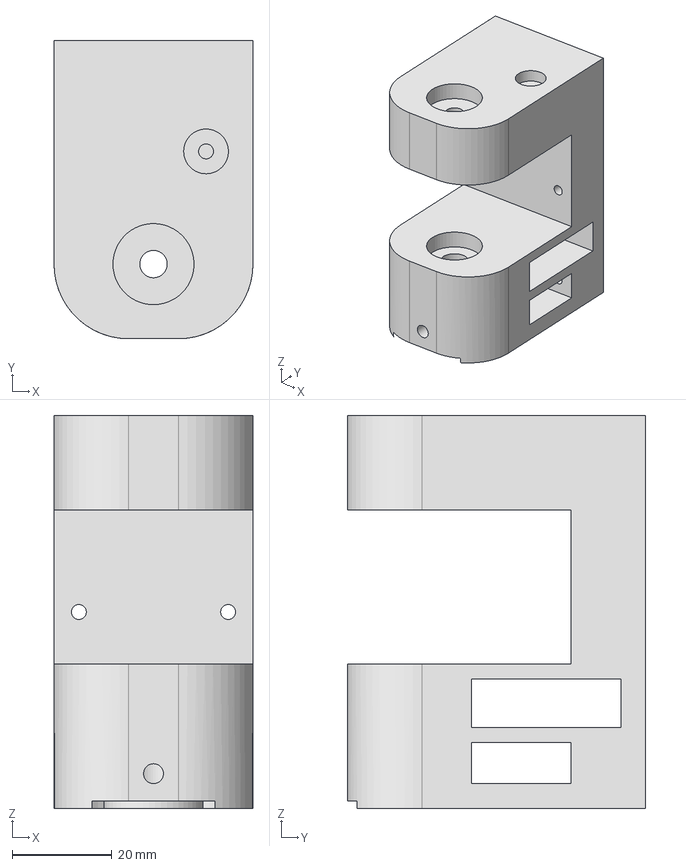
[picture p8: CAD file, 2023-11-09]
hardware/CAD/Gimbal_1.stp
40.0 x 60.0 x 79.0 mm

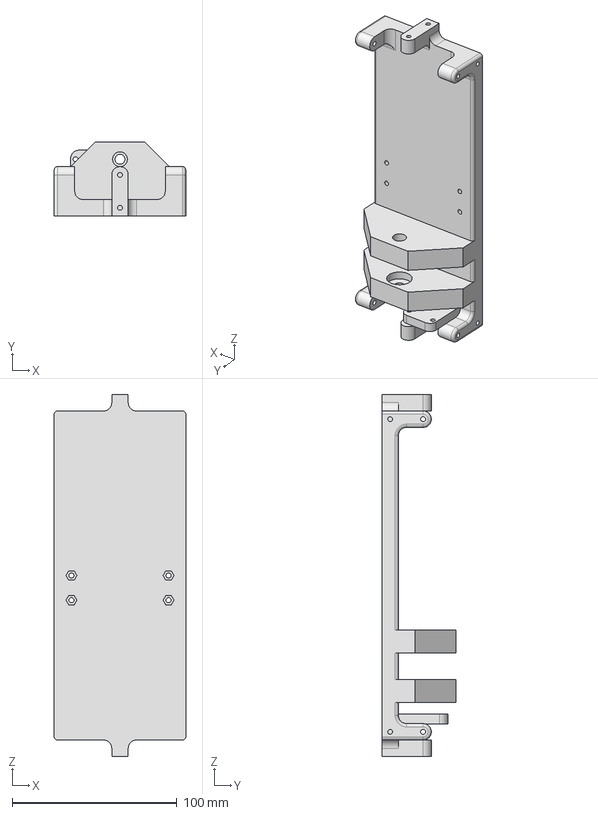
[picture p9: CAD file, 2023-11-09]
hardware/CAD/Base.stp
80.0 x 45.0 x 220.0 mm

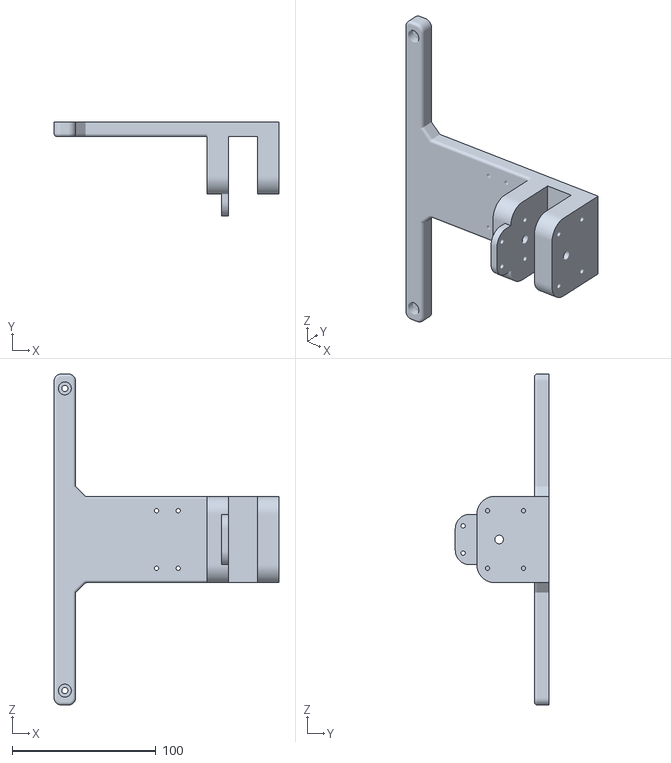
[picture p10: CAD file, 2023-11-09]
hardware/CAD/PanelBarcket_2.stl
156.2 x 65.0 x 230.0

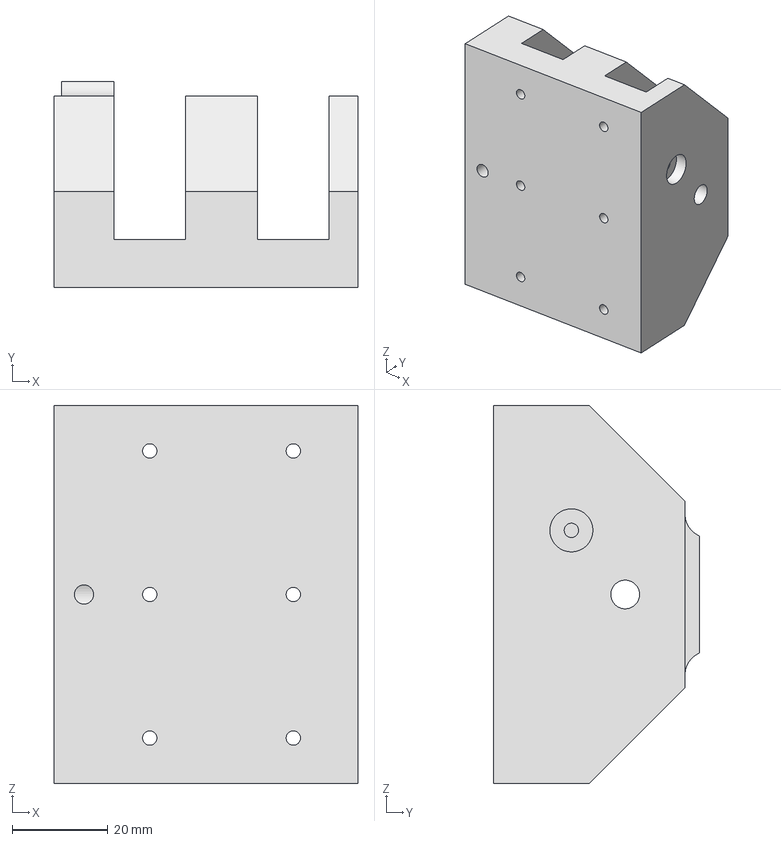
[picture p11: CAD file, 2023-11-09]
hardware/CAD/Gimbal_2.stp
63.5 x 43.0 x 79.0 mm

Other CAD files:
hardware/CAD/Assembly3.iam
hardware/CAD/Base.ipt
hardware/CAD/Base.stl
hardware/CAD/Bearing_mount.ipt
hardware/CAD/CenterSupport.ipt
hardware/CAD/Gimbal_1.ipt
hardware/CAD/Gimbal_1.stl
hardware/CAD/Gimbal_2.ipt
hardware/CAD/Gimbal_2.stl
hardware/CAD/OldVersions/Assembly3.0035.iam
hardware/CAD/OldVersions/Base.0040.ipt
hardware/CAD/OldVersions/Bearing_mount.0001.ipt
hardware/CAD/OldVersions/CenterSupport.0002.ipt
hardware/CAD/OldVersions/Gimbal_1.0034.ipt
hardware/CAD/OldVersions/Gimbal_2.0033.ipt
hardware/CAD/OldVersions/PanelBarcket.0017.ipt
hardware/CAD/OldVersions/PanelBarcket_2.0029.ipt
hardware/CAD/OldVersions/StepperMotorHolder.0044.ipt
hardware/CAD/OldVersions/legs.0007.ipt
hardware/CAD/PanelBarcket.ipt
hardware/CAD/PanelBarcket_2.ipt
hardware/CAD/StepperMotorHolder.ipt
hardware/CAD/legs.ipt

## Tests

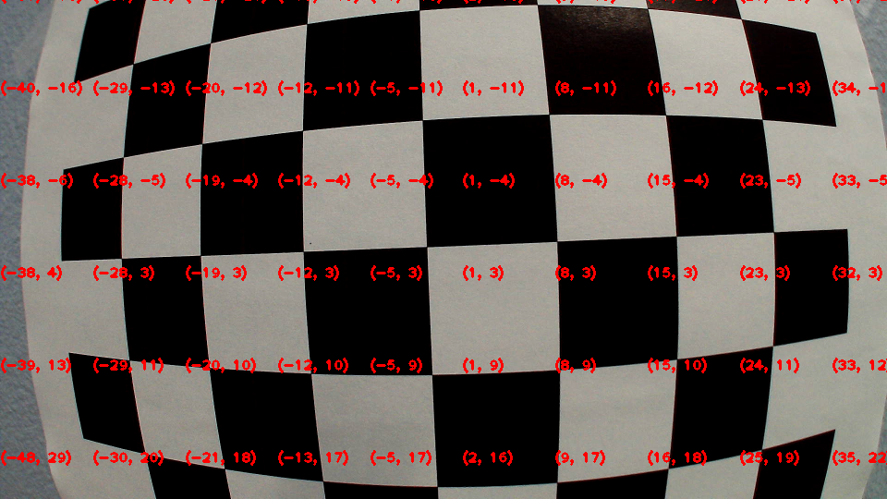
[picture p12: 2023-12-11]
software/Calibration_Codes_Images/frame_labelled.png

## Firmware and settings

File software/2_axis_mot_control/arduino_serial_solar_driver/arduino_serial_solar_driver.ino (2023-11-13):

#include <TMC2209.h>
//MUST INSTQALL TMC2209 by Peter Polidoro

// This example will not work on Arduino boards without HardwareSerial ports,
// such as the Uno, Nano, and Mini.
//
// See this reference for more details:
// https://www.arduino.cc/reference/en/language/functions/communication/serial/
//
// To make this library work with those boards, refer to this library example:
// examples/UnidirectionalCommunication/SoftwareSerial

HardwareSerial & serial_stream = Serial3;

#define PWR_LOG_INTERVAL 5000

const uint8_t STEP_PIN = 5; //7
const uint8_t DIRECTION_PIN = 4; //6
const uint8_t STEP_PIN_TOP = 7; //7
const uint8_t DIRECTION_PIN_TOP = 6; //6

const uint8_t TOP_TMR_PIN = 11;
const uint8_t BOTTOM_TMR_PIN = 9;


const int max_angle_top = 275;
const int min_angle_top = -600;
const int max_angle_bottom = 275;
const int min_angle_bottom = -275;

int current_angle_top = 0;
int current_angle_bottom = 0;

int desired_angle_top = 0;
int desired_angle_bottom = 0;


String s_serial_input = "";
uint8_t u8_serial_in_receipt = 0;

unsigned long timer1_time = 0; //timer for periodic voltage measurment of panel when not moving.

// current values may need to be reduced to prevent overheating depending on
// specific motor and power supply voltage
const uint8_t RUN_CURRENT_PERCENT = 50;


// Instantiate TMC2209
TMC2209 stepper_driver;

void setup()
{
  Serial.begin(115200);
  stepper_driver.setup(serial_stream);

  pinMode(STEP_PIN, OUTPUT);
  pinMode(DIRECTION_PIN, OUTPUT);
    pinMode(STEP_PIN_TOP, OUTPUT);
  pinMode(DIRECTION_PIN_TOP, OUTPUT);

  pinMode(TOP_TMR_PIN, INPUT);
  digitalWrite(TOP_TMR_PIN, HIGH);
  pinMode(BOTTOM_TMR_PIN, INPUT);
  digitalWrite(BOTTOM_TMR_PIN, HIGH);

  stepper_driver.setRunCurrent(RUN_CURRENT_PERCENT);
  stepper_driver.setHoldCurrent(20);
  stepper_driver.disableCoolStep();
  stepper_driver.disableStealthChop();
  stepper_driver.setMicrostepsPerStep(2); //10000 steps per revolution // 27.7 ... ~28 steps per degree. 
  stepper_driver.setStandstillMode(stepper_driver.NORMAL);
  stepper_driver.enable();

  calibrateTopMotorAndCenter();
  calibrateBottomMotorAndCenter();
  calibrateTopMotorAndCenter();
  calibrateBottomMotorAndCenter();

  Serial.print("r");
}

void loop()
{

  if(timer1_time <= millis()){
    timer1_time = millis() + PWR_LOG_INTERVAL;
    uint32_t read_avg = 0;
    for (int i = 0; i < 50; i++){
      read_avg += analogRead(A0);
      delay(10);
    }//measure over 500ms.
    Serial.print('p');
    char buf[5];
    sprintf( buf, "%04d", read_avg/50);
    Serial.print( buf );
    Serial.print('q');

  }
 
if(Serial.available()){
  char r = Serial.read();
  if(r == 'a' && u8_serial_in_receipt == 0){
    u8_serial_in_receipt = 1;
    s_serial_input = "";
    }else if(r == 'b' && u8_serial_in_receipt == 1){
      u8_serial_in_receipt = 2;
      Serial.print('c');
      }else if(u8_serial_in_receipt == 1){
        s_serial_input += r;
        }
  }

  if(u8_serial_in_receipt == 2){
    String receivedString = s_serial_input;
    // Variables to store the split numbers

    // Find the position of the comma in the string
    int commaIndex = receivedString.indexOf(',');

    if (commaIndex != -1) {
      // Extract the substrings from the received string
      String firstNumberString = receivedString.substring(0, commaIndex);
      String secondNumberString = receivedString.substring(commaIndex + 1);

      // Convert the substrings to integers
      desired_angle_top = firstNumberString.toInt();
      desired_angle_bottom = secondNumberString.toInt();

    }
    u8_serial_in_receipt = 0;
    }

  if(desired_angle_top >= min_angle_top && desired_angle_top <= max_angle_top && desired_angle_bottom >= min_angle_bottom && desired_angle_bottom <= max_angle_bottom){

      int angle_to_move_top = desired_angle_top - current_angle_top;
      int angle_to_move_bottom = desired_angle_bottom - current_angle_bottom;

      if(angle_to_move_top !=0 || angle_to_move_bottom != 0){
      moveAngleTop(angle_to_move_top);
      moveAngleBottom(angle_to_move_bottom);
      
      current_angle_top = desired_angle_top;
      current_angle_bottom = desired_angle_bottom;

      Serial.print('d');
  
  }

    
    }

    

 
}

void moveAngleTop(int angle){
  if(angle < 0){
    digitalWrite(DIRECTION_PIN_TOP, HIGH);
    angle = angle * -1;
    }else if(angle > 0){
      digitalWrite(DIRECTION_PIN_TOP, LOW);
      }
    int steps = (int)(2.77*(float)angle);
     for(int i=0; i<steps; i++){
       digitalWrite(STEP_PIN_TOP, HIGH);
    delay(1);
    digitalWrite(STEP_PIN_TOP, LOW);
    delay(4);
      } 
  }

void moveAngleBottom(int angle){
  if(angle < 0){
    digitalWrite(DIRECTION_PIN, HIGH);
    angle = angle * -1;
    }else if (angle > 0){
      digitalWrite(DIRECTION_PIN, LOW);
      }
  int steps = (int)(2.77*(float)angle);
     for(int i=0; i<steps; i++){
       digitalWrite(STEP_PIN, HIGH);
    delay(1);
    digitalWrite(STEP_PIN, LOW);
    delay(4);
      } 
  }


void calibrateTopMotorAndCenter(){
    int counter = 0;
    
  //if clockwise rotated then sensor will be LOW
  if(digitalRead(TOP_TMR_PIN) == LOW){
      digitalWrite(DIRECTION_PIN_TOP, HIGH); //CCW 
   while(counter < 2500){
    counter++;
    digitalWrite(STEP_PIN_TOP, HIGH);
    delay(1);
    digitalWrite(STEP_PIN_TOP, LOW);
    delay(4);

    if(digitalRead(TOP_TMR_PIN) == HIGH){
 //     Serial.println("TMR TOP DETECTED");
      break;
      }
    }
 
  }else{//if ccw rotated the sensor will be HIGH.
      digitalWrite(DIRECTION_PIN_TOP, LOW); //CW 
    while(counter < 2500){
    counter++;
    digitalWrite(STEP_PIN_TOP, HIGH);
    delay(1);
    digitalWrite(STEP_PIN_TOP, LOW);
    delay(4);

    if(digitalRead(TOP_TMR_PIN) == LOW){
    //  Serial.println("TMR TOP DETECTED");
      break;
      }
    }
    }
    delay(500); 
    //Move position to exactly vertical
    digitalWrite(DIRECTION_PIN_TOP, HIGH); //CCW 
    for(int i=0; i<280; i++){
       digitalWrite(STEP_PIN_TOP, HIGH);
    delay(1);
    digitalWrite(STEP_PIN_TOP, LOW);
    delay(4);
      } 
  }

  
void calibrateBottomMotorAndCenter(){
    int counter = 0;
    
  //if CCW rotated then sensor will be LOW
  if(digitalRead(BOTTOM_TMR_PIN) == LOW){
      digitalWrite(DIRECTION_PIN, LOW); //CW 
   while(counter < 2500){
    counter++;
    digitalWrite(STEP_PIN, HIGH);
    delay(1);
    digitalWrite(STEP_PIN, LOW);
    delay(4);

    if(digitalRead(BOTTOM_TMR_PIN) == HIGH){
   //   Serial.println("TMR BOTTOM DETECTED");
      break;
      }
    }
 
  }else{//if cw rotated the sensor will be HIGH.
      digitalWrite(DIRECTION_PIN, HIGH); //CCW 
    while(counter < 2500){
    counter++;
    digitalWrite(STEP_PIN, HIGH);
    delay(1);
    digitalWrite(STEP_PIN, LOW);
    delay(4);

    if(digitalRead(BOTTOM_TMR_PIN) == LOW){
    //  Serial.println("TMR BOTTOM DETECTED");
      break;
      }
    }
    }
    delay(500); 
    //Move position to exactly vertical
    digitalWrite(DIRECTION_PIN, LOW); //CW 
    for(int i=0; i<360; i++){
       digitalWrite(STEP_PIN, HIGH);
    delay(1);
    digitalWrite(STEP_PIN, LOW);
    delay(4);
      } 
  }

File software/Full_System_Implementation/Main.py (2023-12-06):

from SunPositionDrawer import SunPositionDrawer
from ArduinoSerialInterface import ArduinoSerialInterface, ArduinoSerialInterfaceTesting
from CloudSegmentation import CloudSegmentation
from WeatherChecker import WeatherChecker
from WeatherPredictor import predict_weather
import time
import joblib
import matplotlib.pyplot as plt
import cv2

doNotRotate = False

class Main:
    def __init__(self, location_city, api_weather, svm_classifier):
        plt.ion()  # Enable interactive mode
        self.sun_drawer = SunPositionDrawer()
        self.arduino_interface = ArduinoSerialInterface() #ArduinoSerialInterfaceTesting() 
        self.cloud_segmentation = CloudSegmentation()
        self.weather_checker = WeatherChecker(api_weather, location_city)
        self.svm_classifier = joblib.load(svm_classifier_path)

    def periodic_task_10_second(self):
        print("10s timer")
        cv2.destroyAllWindows()

        # Check the weather using the API
        weather_data = self.weather_checker.get_weather()  # Corrected method name
        api_bad_weather = self.weather_checker.is_bad_weather(weather_data)

        # Use CloudSegmentation to capture and process clouds
        self.cloud_segmentation.capture_image()
        self.cloud_segmentation.processForClouds()

        # Use the camera for weather prediction
        ret, frame = self.cloud_segmentation.get_captured_image()
        if ret:
            weather = predict_weather(frame, self.svm_classifier)
            print("Predicted weather:", weather)
            camera_sunny_weather = weather == "Sunny"
        else:
            camera_sunny_weather = True  # Default to sunny if camera fails
        # Decide the action based on API and camera weather data
        if api_bad_weather and not camera_sunny_weather:
            self.arduino_interface.moveToAngle(-59.0, 0)
            print("Non-sunny or bad weather detected, adjusting solar panel.")
        elif not camera_sunny_weather:
            self.arduino_interface.moveToAngle(0.0, 0.0)
        else:
            if(doNotRotate == False):
                self.arduino_interface.moveToAngle(self.sun_drawer.getRotX(), self.sun_drawer.getRotY())
                self.cloud_segmentation.setErrAngle(self.sun_drawer.getRotXErr(), self.sun_drawer.getRotYErr())

    def periodic_task_2_second(self):
        print(f"CLAMPED: yaw (x):{self.sun_drawer.getRotX()}, pitch(y):{self.sun_drawer.getRotY()}")
        print(f"ERR    : yaw (x):{self.sun_drawer.getRotXErr()}, pitch(y):{self.sun_drawer.getRotYErr()}")

    def run(self):
        last_called = time.time()
        last_called_2 = time.time()
        print("waiting for hardware startup")
        while True:
            cv2.waitKey(1)  # Waits 1ms
            self.arduino_interface.run()
            if (self.arduino_interface.isDevReady()):
                self.sun_drawer.run()
                if time.time() - last_called_2 > 2:
                    self.periodic_task_2_second()
                    last_called_2 = time.time()
                if time.time() - last_called > 10:
                    self.periodic_task_10_second()  # Call the periodic function
                    last_called = time.time()  # Reset the timer


if __name__ == "__main__":
    svm_classifier_path = './svm_classifier.joblib'  # update the path
    svm_classifier = joblib.load(svm_classifier_path)
    main = Main(location_city='Los Angeles', api_weather='32b8600ccd902c30801c6fe5ac806afa',
                svm_classifier=svm_classifier)
    main.run()

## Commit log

2023-11-09 -Arduino Code initial
2023-11-09 -Cad design files commit
    [Assembly3.0035.iam, Assembly3.iam, Base.0040.ipt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]
2023-11-11 -Python and Arduino Serial communcation using PySerial
    -Implemented comm from python to Arduino to control the solar panel angle.
2023-11-11 -Set mechanical angle limit for firmware. Preventing mechanical damage.
    [arduino_serial_solar_driver.ino]
2023-11-11 -Added further communication feedback from motor control
    -r means ready at startup
    -c means confirm receipt of message
    -d means done movement.
2023-11-11 Create raspberry_weather_cloud_detection
2023-11-13 -Live Voltage logging implemented
    -Voltage divider -> ADC -> Converted Voltage reading displayed live.
2023-11-17 Create Attempt 1
    Attempting to calibrate the camera based on parameters and also map the azimuth and zenith angles to pixel ratios of the camera. This code assumes a linear mapping of the camera's field of view
2023-11-17 Create Attempt 2
    This code snippet performs camera calibration using checkerboard calibration images to obtain the camera matrix (mtx) and distortion coefficients (dist). Then, it validates the mapping accuracy by comparing the calculated pixel coordinates with the validation data for specific angles.
    Replace the validation_azimuth_deg, validation_zenith_deg, and validation_pixels lists with actual validation data, where validation_azimuth_deg and validation_zenith_deg are the validation angles, and validation_pixels contains corresponding measured or ground truth pixel coordinates.
2023-11-20 -Calibration Scripts
    -Various scripts for capturing and generating the angle matrix.
2023-11-20 -Calculating rotation around x and y axis as the mechanical system will be able to move.
2023-11-20 -current time rather than testing time.
2023-11-21 -Clamped values for algorithm
2023-11-24 -Further progress
    -Cloud segmentation image capture
    -Serial interface bug correction.
    [ArduinoSerialInterface.py, CloudSegmentation.py, Main.py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]
2023-11-24 -Calibration Matrix Angle Extraction
2023-11-25 Update and rename raspberry_weather_cloud_detection.py to YOLOCloudDetector.py
2023-11-26 -Code test on hardware
    -Fixed angle calculations arctan2->arctan
    -Serial communication fixes.
    -Started implementing angle clamp difference to be able to locate sun on camera image.
    [ArduinoSerialInterface.py, CloudSegmentation.py, Main.py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]
2023-11-26 -Error due to clamp calcualtion for position of sun on image.
    [Main.py, SunPositionDrawer.py]
2023-11-28 change ArduinoSerialInterface.py
2023-11-30 -Able to run without arduino
2023-12-01 -updated pandas to support latest version.
    -Fixed resistor values.
    [ArduinoSerialInterface.py]
2023-12-01 update resistance
2023-12-04 Update report.Financial Projections.Graphmd
    Insert the graph
2023-12-11 -regenerated calibration visulaization
